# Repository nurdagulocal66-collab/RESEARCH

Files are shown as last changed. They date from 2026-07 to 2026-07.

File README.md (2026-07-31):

# RESEARCH
Bu proje, çok kademeli güç yönetimi ve regülasyon işlemlerini tek bir kart üzerinde toplamak amacıyla geliştirilmiş kapsamlı bir donanım tasarımının şematik altyapısını oluşturmaktadır. Çalışma prensibi olarak sistem, ana giriş gerilimini LM5576 tabanlı anahtarlamalı regülatör (buck converter) yapısı kullanarak verimli bir şekilde düşürmekte ve 500 kHz anahtarlama frekansı hedefiyle güç ağını beslemektedir. Elde edilen bu ara gerilim seviyelerinin ardından, kart üzerinde konumlandırılan LM1117-5.0 ve LT1117-3.3 lineer regülatörler (LDO) aracılığıyla hassas devreler ve mikrodenetleyici birimleri için kararlı 5V ve 3.3V DC besleme rayları türetilmektedir. Tasarımda yer alan IR2101 gate sürücü ve STP75NF75 güç MOSFET yapıları ile M7-HT diyotlar gibi çevre elemanlar ise doğrudan regülasyon döngüsünü destekleyen anahtarlama ve kontrol kademelerini oluşturmakta, ayrıca devredeki TestPoint noktaları ve montaj padleri sistemin test edilebilirliğini ve fiziksel kararlılığını güvence altına almaktadır.

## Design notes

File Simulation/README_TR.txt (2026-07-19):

XL7015 LTspice dosyaları

1) XL7015.lib ve XL7015.asy dosyalarını, devrenizin .asc dosyasıyla aynı klasöre koyun.
2) LTspice'ı kapatıp yeniden açın.
3) F2 -> Top Directory açılır menüsünden proje klasörünü seçin.
4) XL7015 sembolünü yerleştirin.
5) Şemaya şu komutu ekleyin:
   .include XL7015.lib

Pin sırası:
1 VIN
2 SW
3 GND
4 FB
5 EN

5 V örnek dış devre:
VIN: 24 V
CIN: 33uF (VIN-GND)
L1: 100uH (SW-VOUT)
D1: S310, anot GND, katot SW
COUT: 100uF (VOUT-GND)
R2: 10k (VOUT-FB)
R1: 3.3k (FB-GND)
CFF: 33nF (VOUT-FB)
EN: GND
Yük: örneğin 50 ohm (yaklaşık 100 mA)
Transient: .tran 0 30m 0 100n startup

Not:
Bu dosya resmi üretici modeli değildir. Temel PWM ve regülasyon davranışını görmek
için hazırlanmış basitleştirilmiş eğitim modelidir; gerçek verim, geçici rejim,
korumalar ve kararlılık doğrulaması için datasheet ölçümleri esas alınmalıdır.

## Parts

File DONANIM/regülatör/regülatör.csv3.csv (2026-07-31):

Id | Designator | Footprint | Quantity | Designation | Supplier and ref
1 | R4,R5,R6 | R_0201_0603Metric | 3 | 330R
2 | R2 | R_0805_2012Metric | 1 | 470k
3 | R22,R20,R35,R21 | R_0805_2012Metric | 4 | 10
4 | R60 | R_0805_2012Metric | 1 | 0R
5 | R18 | R_0805_2012Metric | 1 | 47k
6 | R3 | R_0805_2012Metric | 1 | 16k
7 | R47 | R_0805_2012Metric | 1 | 1k
8 | R7,R8 | R_0805_2012Metric | 2 | 4.7k
9 | R9 | R_0805_2012Metric | 1 | 0
10 | R17 | R_0805_2012Metric | 1 | 4.99k
11 | R16 | R_0805_2012Metric | 1 | 69.8k
12 | R23 | R_0805_2012Metric | 1 | 22
13 | R1 | R_0201_0603Metric | 1 | 196k
14 | R32,R9 | R_4020_10251Metric | 2 | 2m
15 | C4 | CP_Radial_D10.0mm_P5.00mm | 1 | 10uF 100V
16 | J3 | TerminalBlock_Phoenix_MKDS-1,5-2_1x02_P5.00mm_Horizontal | 1 | 5V
17 | C6,C5 | C_0805_2012Metric | 2 | 100nF 100V
18 | J5 | TerminalBlock_Phoenix_MKDS-1,5-2_1x02_P5.00mm_Horizontal | 1 | MCU GİRİŞİ
19 | TP2,TP1,TP4,TP3 | TestPoint_Pad_D2.0mm | 4 | TestPoint
20 | C28,C10 | CP_Elec_4x5.3 | 2 | 22uF 10V
21 | Q2,Q1 | PinSocket_1x03_P2.54mm_Vertical | 2 | STP75NF75
22 | C1,C40 | C_0805_2012Metric | 2 | 100nF 25V
23 | D11 | D_SMB | 1 | SMBJ58A
24 | C41,C9,C27 | CP_Elec_5x5.3 | 3 | 10uF 35V
25 | J2 | TerminalBlock_Phoenix_MKDS-1,5-2_1x02_P5.00mm_Horizontal | 1 | 12V
26 | C11,C12 | C_0805_2012Metric | 2 | 100nF 25v
27 | D8,D7 | LED_0805_2012Metric | 2 | LED_kırmızı
28 | C3,C7 | CP_Radial_D8.0mm_P5.00mm | 2 | 47uF 25V
29 | D3,D6 | D_SMA | 2 | US1M-13-F
30 | J7,J8 | TerminalBlock_Phoenix_MKDS-1,5-2_1x02_P5.00mm_Horizontal | 2 | LOAD
31 | J4 | TerminalBlock_Phoenix_MKDS-1,5-2_1x02_P5.00mm_Horizontal | 1 | 3V3
32 | C2 | C_0805_2012Metric | 1 | 22pF 25V
33 | U6 | SOT-223-3_TabPin2 | 1 | LM1117S-5.0
34 | D9,D5 | D_SOD-123 | 2 | 1N4148W
35 | F1 | Fuse_Littelfuse_395Series | 1 | 2A 125V Slow-Blow
36 | C20 | CP_Elec_4x5.3 | 1 | 1uF 50V
37 | U7 | SOT-223-3_TabPin2 | 1 | LT1117-3.3
38 | C16 | C_0805_2012Metric | 1 | 4.7nF 25V
39 | D2 | D_SOD-128 | 1 | PMEG6030EVP
40 | U5 | SOIC-8_3.9x4.9mm_P1.27mm | 1 | IR2101
41 | J6 | TerminalBlock_Phoenix_MKDS-1,5-2_1x02_P5.00mm_Horizontal | 1 | MOSFET ÇIKIŞLARI
42 | L2 | L_12x12mm_H8mm | 1 | 24uH
43 | C26 | CP_Radial_D10.0mm_P5.00mm | 1 | 100uF 100V
44 | J1 | TerminalBlock_Phoenix_MKDS-1,5-2_1x02_P5.00mm_Horizontal | 1 | GÜÇ GİRİŞİ
45 | U1 | TI_SO-PowerPAD-8_ThermalVias | 1 | TPS54360DDA
46 | R13 | R_0201_0603Metric | 1 | 1k
47 | D1 | LED_0805_2012Metric | 1 | LED

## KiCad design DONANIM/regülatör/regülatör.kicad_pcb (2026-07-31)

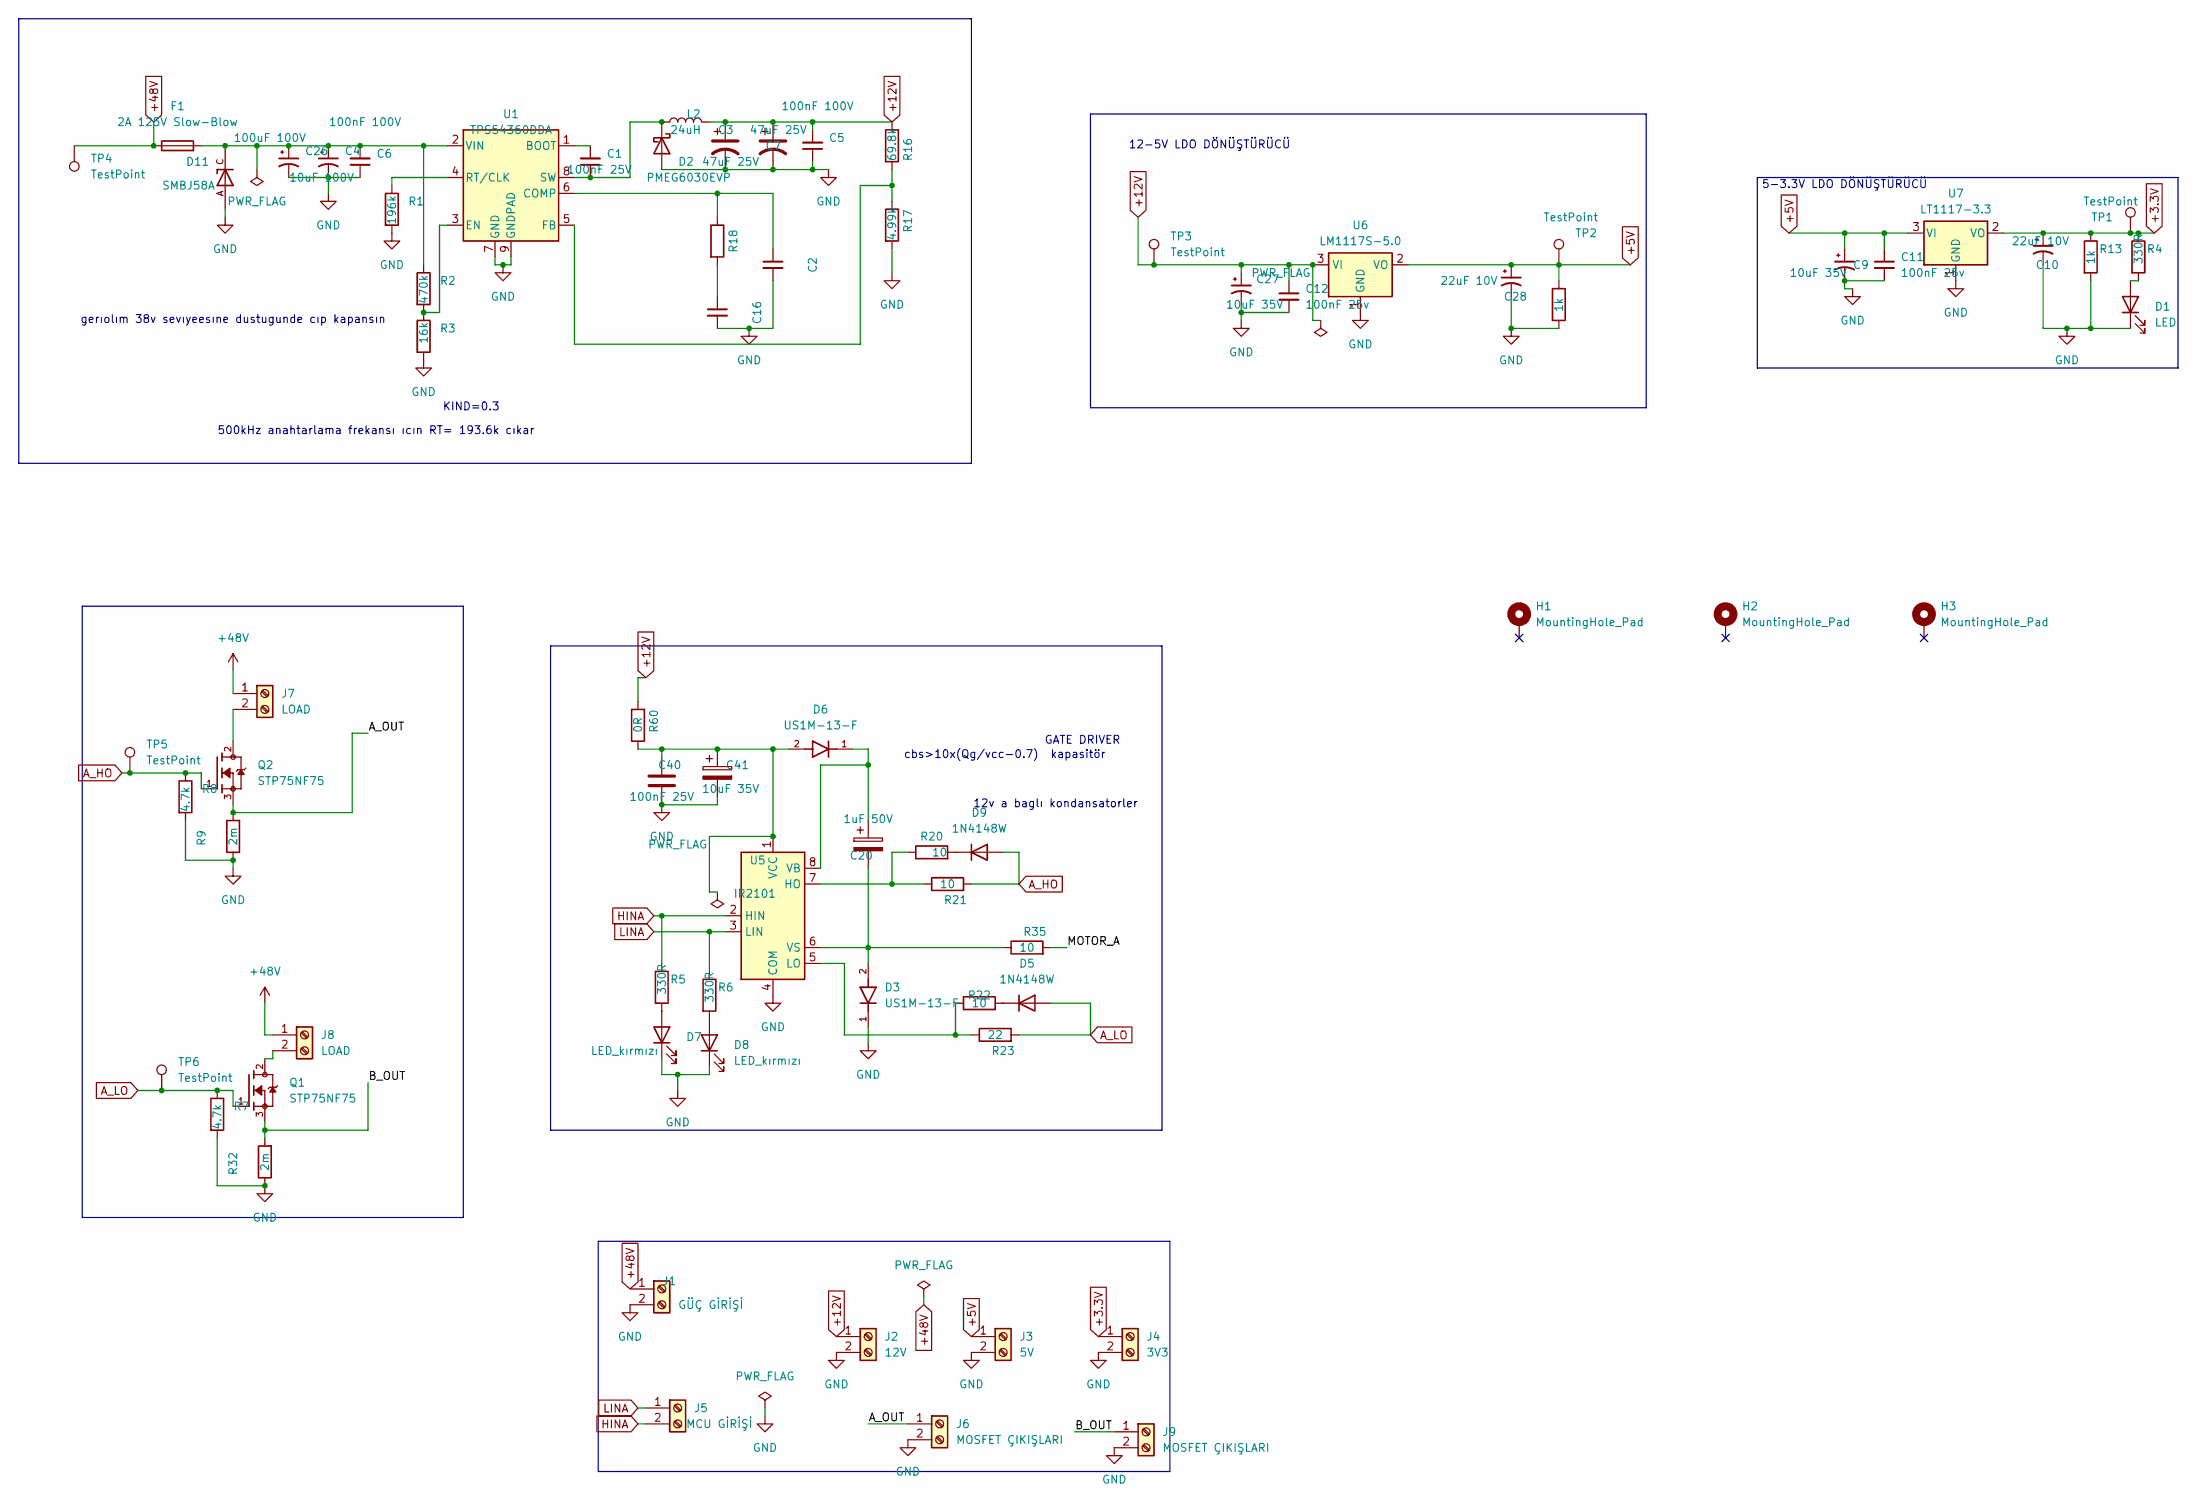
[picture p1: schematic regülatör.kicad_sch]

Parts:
C1, C40: 100nF 25V; C_0805_2012Metric
C2: 22pF 25V; C_0402_1005Metric
C3, C7: 47uF 25V; CP_Radial_D8.0mm_P5.00mm
C4: 10uF 100V; CP_Radial_D10.0mm_P5.00mm
C5: 100nF 100V; C_0805_2012Metric
C6: 100nF 100V; C_1206_3216Metric
C9, C27, C41: 10uF 35V; CP_Elec_5x5.3
C10, C28: 22uF 10V; CP_Elec_4x5.3
C11, C12: 100nF 25v; C_0805_2012Metric
C16: 4.7nF 25V; C_0805_2012Metric
C20: 1uF 50V; CP_Elec_4x5.3
C26: 100uF 100V; CP_Radial_D10.0mm_P5.00mm
D1: LED; LED_0805_2012Metric
D2: PMEG6030EVP; D_SOD-128
D3, D6: US1M-13-F; D_SMA; PARTREV 11-2
D5, D9: 1N4148W; D_SOD-123
D7, D8: LED_kırmızı; LED_0805_2012Metric
D11: SMBJ58A; D_SMB; PARTREV F2102
F1: 2A 125V Slow-Blow; Fuse_Littelfuse_395Series
H1, H2, H3: MountingHole_Pad; MountingHole_3.2mm_M3_DIN965_Pad
J1: GÜÇ GİRİŞİ; TerminalBlock_Phoenix_MKDS-1,5-2_1x02_P5.00mm_Horizontal
J2: 12V; TerminalBlock_Phoenix_MKDS-1,5-2_1x02_P5.00mm_Horizontal
J3: 5V; TerminalBlock_Phoenix_MKDS-1,5-2_1x02_P5.00mm_Horizontal
J4: 3V3; TerminalBlock_Phoenix_MKDS-1,5-2_1x02_P5.00mm_Horizontal
J5: MCU GİRİŞİ; TerminalBlock_Phoenix_MKDS-1,5-2_1x02_P5.00mm_Horizontal
J6, J9: MOSFET ÇIKIŞLARI; TerminalBlock_Phoenix_MKDS-1,5-2_1x02_P5.00mm_Horizontal
J7, J8: LOAD; TerminalBlock_Phoenix_MKDS-1,5-2_1x02_P5.00mm_Horizontal
L2: 24uH; L_12x12mm_H8mm
Q1, Q2: STP75NF75; PinSocket_1x03_P2.54mm_Vertical
R1: 196k; R_0603_1608Metric
R2: 470k; R_0805_2012Metric
R3: 16k; R_0805_2012Metric
R4, R5, R6: 330R; R_0603_1608Metric
R7, R8: 4.7k; R_0805_2012Metric
R9, R32: 2m; R_4020_10251Metric
R13: 1k; C_0402_1005Metric
R16: 69.8k; R_0805_2012Metric
R17: 4.99k; R_0805_2012Metric
R18: 47k; R_0805_2012Metric
R20, R21, R22, R35: 10; R_0805_2012Metric
R23: 22; R_0805_2012Metric
R47: 1k; R_0805_2012Metric
R60: 0R; R_0805_2012Metric
TP1, TP2, TP3, TP4, TP5, TP6: TestPoint; TestPoint_Pad_D2.0mm
U1: TPS54360DDA; TI_SO-PowerPAD-8_ThermalVias
U5: IR2101; SOIC-8_3.9x4.9mm_P1.27mm
U6: LM1117S-5.0; SOT-223-3_TabPin2
U7: LT1117-3.3; SOT-223-3_TabPin2

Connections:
+3.3V: C10.1, J4.1, R4.1, R13.1, TP1.1, U7.2 (VO)
+5V: C9.1, C11.1, C28.1, J3.1, R47.1, TP2.1, U6.2 (VO), U7.3 (VI)
+12V: C3.1, C5.2, C7.1, C12.1, C27.1, J2.1, L2.2, R16.1, R60.2, TP3.1, U6.3 (VI)
+48V: F1.1, J1.1, J7.1, J8.1, TP4.1
/A_OUT: J6.1, Q2.3, R9.2
/B_OUT: J9.1, Q1.3, R32.2
/MOTOR_A: R35.2
A_HO: D9.2 (A), Q2.1, R8.1, R21.2, TP5.1
A_LO: D5.2 (A), Q1.1, R7.1, R23.2, TP6.1
GND: C2.2, C3.2, C4.2, C5.1, C6.1, C7.2, C9.2, C10.2, C11.2, C12.2, C16.2, C26.2, C27.2, C28.2, C40.1, C41.2, D1.1 (K), D2.2 (A), D3.1, D7.1 (K), D8.1 (K), D11.A, J1.2, J2.2, J3.2, J4.2, J6.2, J9.2, R1.2, R3.2, R7.2, R8.2, R9.1, R13.2, R17.2, R32.1, R47.2, U1.7 (GND), U1.9 (GNDPAD), U5.4 (COM), U6.1 (GND), U7.1 (GND)
HINA: J5.2, R5.1, U5.2 (HIN)
LINA: J5.1, R6.1, U5.3 (LIN)
unnamed: C16.1, R18.2
unnamed: D1.2 (A), R4.2
unnamed: C1.1, D2.1 (K), L2.1, U1.8 (SW)
unnamed: D5.1 (K), R22.2
unnamed: D7.2 (A), R5.2
unnamed: D8.2 (A), R6.2
unnamed: D9.1 (K), R20.2
unnamed: J7.2, Q2.2
unnamed: J8.2, Q1.2
unnamed: C1.2, U1.1 (BOOT)
unnamed: C2.1, R18.1, U1.6 (COMP)
unnamed: R2.2, R3.1, U1.3 (EN)
unnamed: R16.2, R17.1, U1.5 (FB)
unnamed: R1.1, U1.4 (RT/CLK)
unnamed: C4.1, C6.2, C26.1, D11.C, F1.2, R2.1, U1.2 (VIN)
unnamed: R20.1, R21.1, U5.7 (HO)
unnamed: R22.1, R23.1, U5.5 (LO)
unnamed: C20.1, D6.1, U5.8 (VB)
unnamed: C40.2, C41.1, D6.2, R60.1, U5.1 (VCC)
unnamed: C20.2, D3.2, R35.1, U5.6 (VS)

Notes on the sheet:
cbs>10x(Qg/vcc-0.7) kapasitör
GATE DRIVER
gerıolım 38v sevıyeesıne dustugunde cıp kapansın
5-3.3V LDO DÖNÜŞTÜRÜCÜ
KIND=0.3
12-5V LDO DÖNÜŞTÜRÜCÜ
12v a baglı kondansatorler
500kHz anahtarlama frekansı ıcın RT= 193.6k cıkar

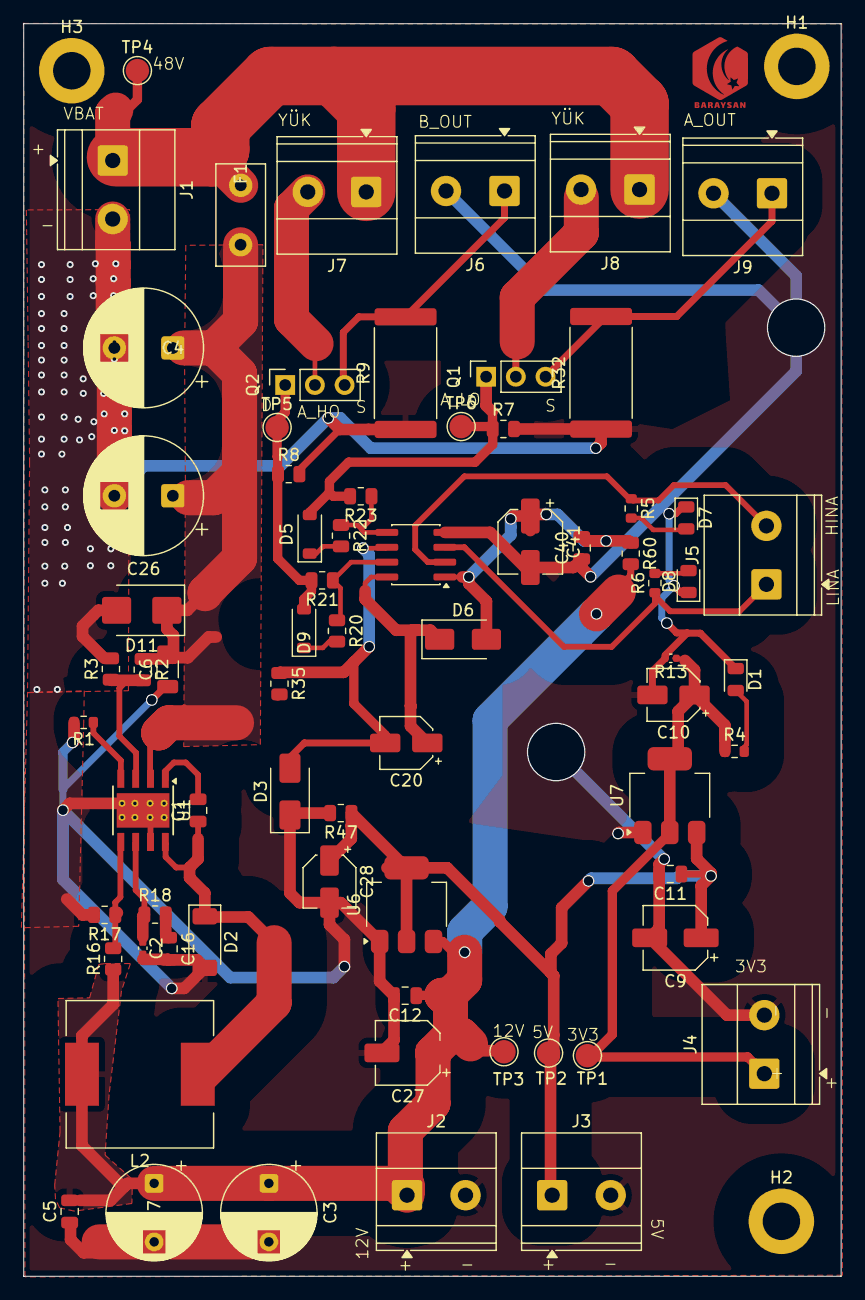
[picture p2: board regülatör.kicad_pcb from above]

Board: 2 copper layers, 69.9 x 107.1 mm, 74 parts (0 on the bottom side), 31 nets.

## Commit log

2026-07-19 Add devre2.asc schematic to Simulation folder
2026-07-19 Add devre2.asc schematic and all component library/model files
2026-07-31 DONANIM klasörü eklendi
    [regülatör-B_Cu.gbr, regülatör-B_Mask.gbr, regülatör-B_Paste.gbr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]
